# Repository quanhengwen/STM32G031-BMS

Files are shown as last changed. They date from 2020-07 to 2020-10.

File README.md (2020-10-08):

## STM32Gx31 BMS Board 
-----------------------------------------------------

### Problem
-------
A DIY Powerwall is the DIY construction of a pack of battery cells to create an energy store which can be used via inverters to power electrical items in the home. Generally cells are salvaged/second hand.

Lithium batteries need to be kept at the same voltage level across a parallel pack. This is done by balancing each cell in the pack to raise or lower its voltage to match the others.

Existing balancing solutions are available in the market place, but at a relatively high cost compared to the cost of the battery bank, so this project is to design a low-cost, simple featured BMS.

### Circuit explanation
------------------
Battery management system controlled by STM32G031K6 32bit microcontroller, the system has three separated units, power supply, analog digital conversion peripheral 
and communication unit. 

Power supply is connected directly to batteries meaning that we do not need additional external power source. Power supply main part is Texas Instruments integrated 
circuit TPS6107x which stands as a buck/boost converter generating stable 600 mA and 3.3 V at the output. All 4.7 uF capacitors connceted to TPS6107x chip are used to give the 
maximum power at the output. Two 4.7 uF X7R capacitors instead of one 10uF capacitor are better solution due to less value noise generation. 

The output voltage of the TPS6107x dc/dc converter can be adjusted with an external resistor divider. The typical value of the voltage at the FB pin is 500 mV. The maximum 
recommended value for the output voltage is 5.5 V. The current through the resistive divider should be about 100 times greater than the current into the FB pin. 

The typical current into the FB pin is 0.01 µA, and the voltage across R2 is typically 500 mV. Based on those two values, the recommended value for R2 should be lower than 500 kΩ, in
order to set the divider current at 1 µA or higher. Because of internal compensation circuitry, the value for this resistor should be in the range of 200 kΩ. The second parameter for
choosing the inductor is the desired current ripple in the inductor. Normally, it is advisable to work with a ripple of less than 20% of the average inductor current. A smaller
ripple reduces the magnetic hysteresis losses in the inductor, as well as  output voltage ripple and EMI. 

But in the same way, regulation time rises at load changes. Parameter f is the switching frequency and ΔIL is the ripple current in the inductor, i.e.,
40% ΔIL. In this example,the desired inductor has the value of 4 µH. With this calculated value and the calculated currents, it is possible to choose a suitable inductor. In typical 
applications, a 4.7-µH inductance is recommended. The device has been optimized to operate with inductance values between 2.2 µH and 10 µH.

Analog to digital conversion peripheral is used to take analog values from various sources, like NTC thermistors and batteries. These sources give us battery voltage and
battery temperature directly from battery connector and from the battery side. These two temperature points are added to calculate the temperature change between battery
connector and battery body. ADC peripheral has an ability to generate 12 bit and 16 bit battery voltage value due to operational amplifier circuit that generates triangle shape
signal making it better for microcontroller to take measurements with 4 extra bits. LMV321 is used as a main operational amplifier.

Devices are communicating in series, sharing measured values between each other. Main CPU is collecting voltage and temperature values from every unit and posting it to 
the PLC. System testing unit is using both half duplex and full duplex communication method. Half duplex method allows the system to communicate with another one but not 
in the same time whereas full duplex is making that possible. 

Half and full duplex communication main elements are Texas Instruments SN65HVD10 and SN65HVD73 transreceivers 
circuits. ICs datasheets recommend 10 kOhms pull up resistors for receiver input line and 10 kOhms pull down resistor for transmitter line. All outputs must be protected 
from electrostatic discharge. ESD protection is made using 10 Ohms resistors and zener diodes with Vz = 5 V disallowing signals to have values greater than 5 V.

### Project Documents 

[STM32G0 NUCLEO User Manual 1](https://www.st.com/resource/en/user_manual/dm00622380-stm32g0-nucleo-32-board-mb1455-stmicroelectronics.pdf)

[STM32G0 NUCLEO User Manual 2](https://www.st.com/resource/en/user_manual/dm00231744-stm32-nucleo32-boards-mb1180-stmicroelectronics.pdf)

[STM32G0 NUCLEO Reference Manual](https://www.st.com/resource/en/reference_manual/dm00371828-stm32g0x1-advanced-armbased-32bit-mcus-stmicroelectronics.pdf)

### KiCad Design 

_BMSv2.0 PCB Layout Design_

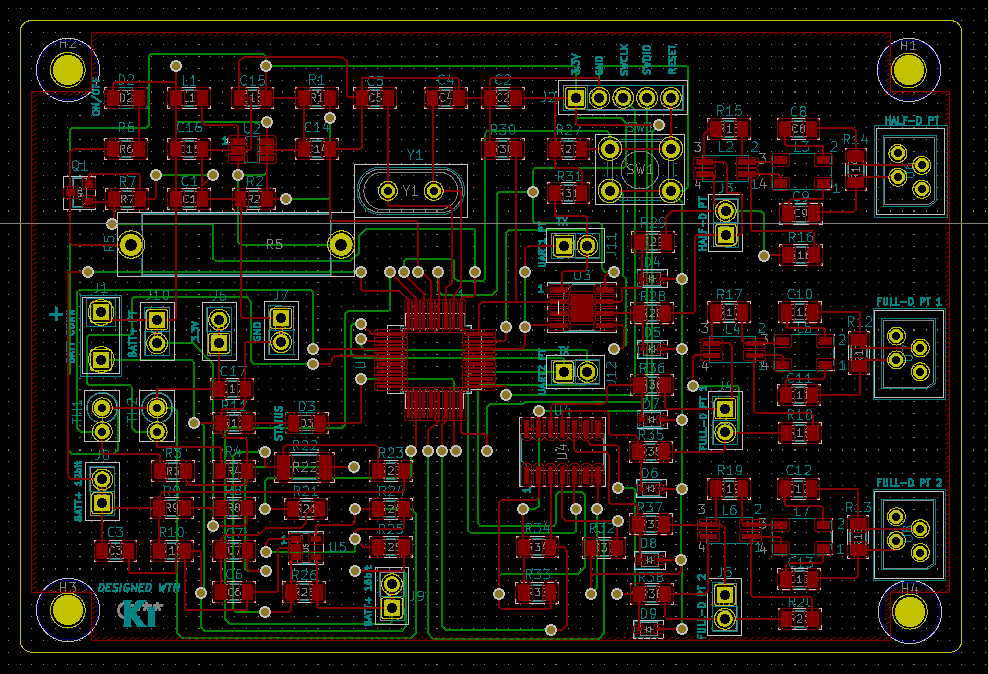
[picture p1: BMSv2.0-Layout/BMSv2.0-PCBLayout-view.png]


_BMSv2.0 PCB 3D View_

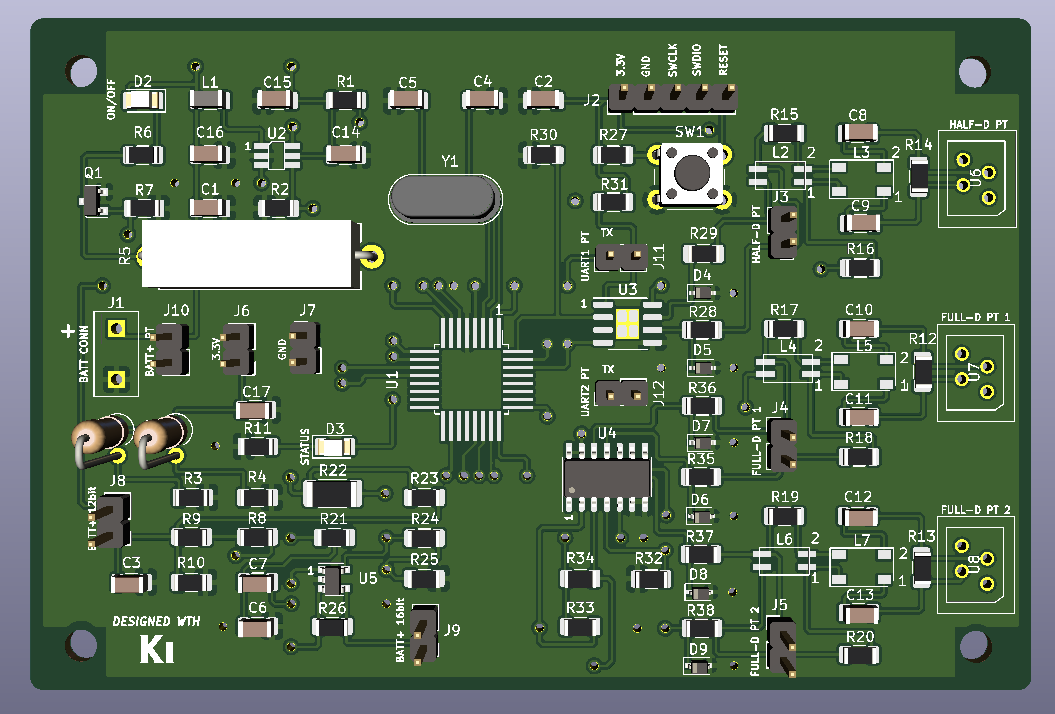
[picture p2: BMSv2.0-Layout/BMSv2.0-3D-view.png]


### Shortcomings and footnotes

1. Replace the boost converter with the buck/boost converter
2. Make the hole in the footprint for communication connector header
3. Replace 200k resistor with 180k resistor in the power supply block to generate correct voltage reference
4. Move the cooper pour layer from the output connectors
5. Put the interface to connect the board with PC
6. Change PWM output pin to TIM2_CH1
7. Move ADC pin from ADC1_IN1 pin (PA1) to clear the conflict with UART2 configuration
8. Using FreeRTOS, one task will take analog voltage and temperature values every milisecond, another task will send the data after it gets the request

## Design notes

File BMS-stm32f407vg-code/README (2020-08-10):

/--------------------------ADC peripheral explanation--------------------------------------
//PA0 and PA1 are analog input pins connected to measure battery voltage
//We assume that at PA0 pin (ADC_VOLT point) will be 16 bit battery voltage value
//at PA1 (ADC_VOLT_IN) will be 12 bit battery voltage value
//PA4 pin (ADC_TEMP1 point) is connected to voltage divider made by 10k resistor and thermistor in series
//PA5 pin (ADC_TEMP2 point) is connected aslo to simmilar voltage divider
//F_CPU is 16 MHz and we need to divide that value to cca 125 kHz to form ADCCLK
//for this purpose, we will use ADCx_SMPRx register (SMPx [2:0]) that holds the value how many cycles will th system sample
//any value and ADCx_CCR register (ADCPRE[17:16]) SMPx = 001 (15 cycles), ADCPRE = 11 ( PCK2 / 8) 
//ADCCLK -> 16 MHz / (15*8) = 133.3 kHz 
//We will allign data to the right so ALIGH bit in ADCx_CR2 will be cleared to 0, VREF is 2.56 V internally

//--------------------------System Nofitications----------------------------------------------
//type 0 for false ondition and 1 for true condition

//--------------------------TIM1 peripheral explanation---------------------------------------
//TIM1 is used to generate clock signal with frquency about 8 Hz, timer mode will be clear at compare match

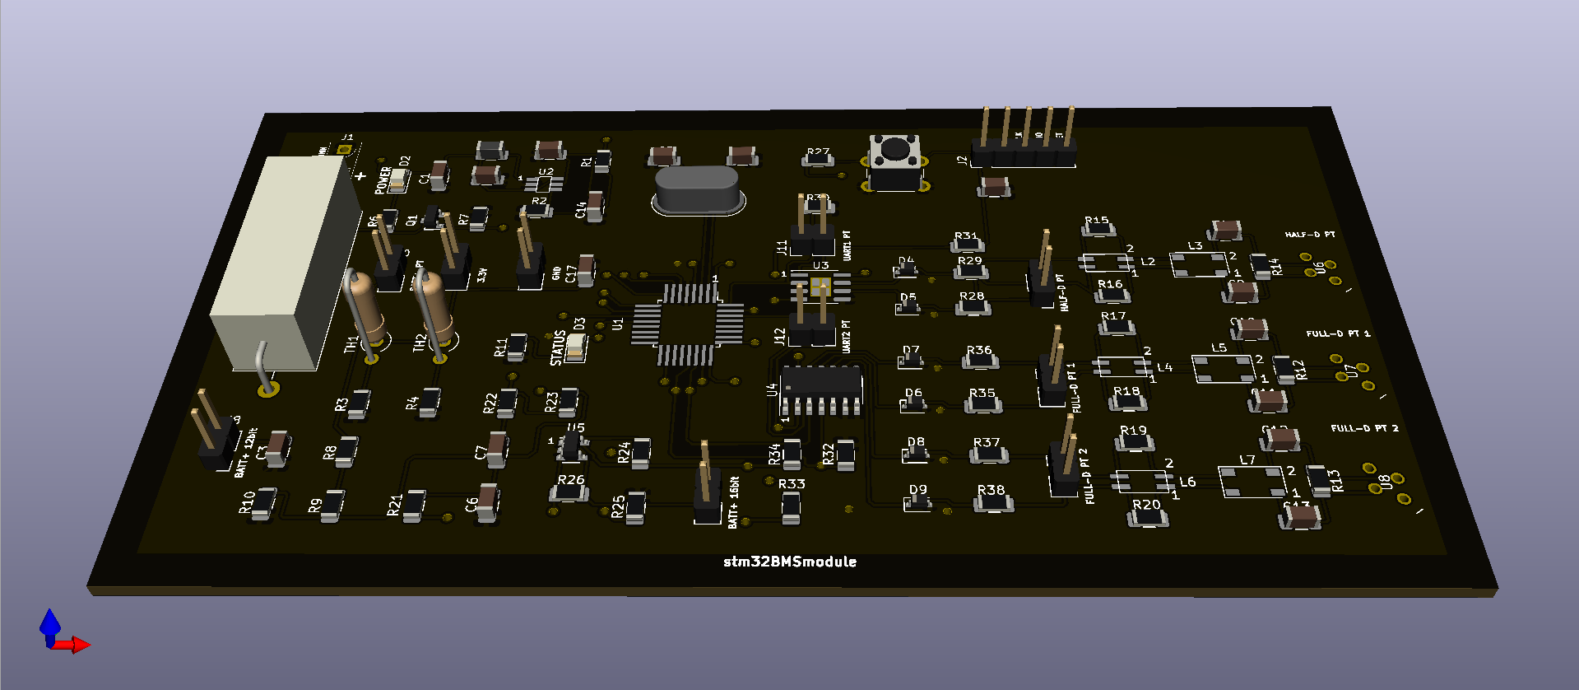
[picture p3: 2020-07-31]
BMS-layer-design-3Dview/STM32_BMS.png

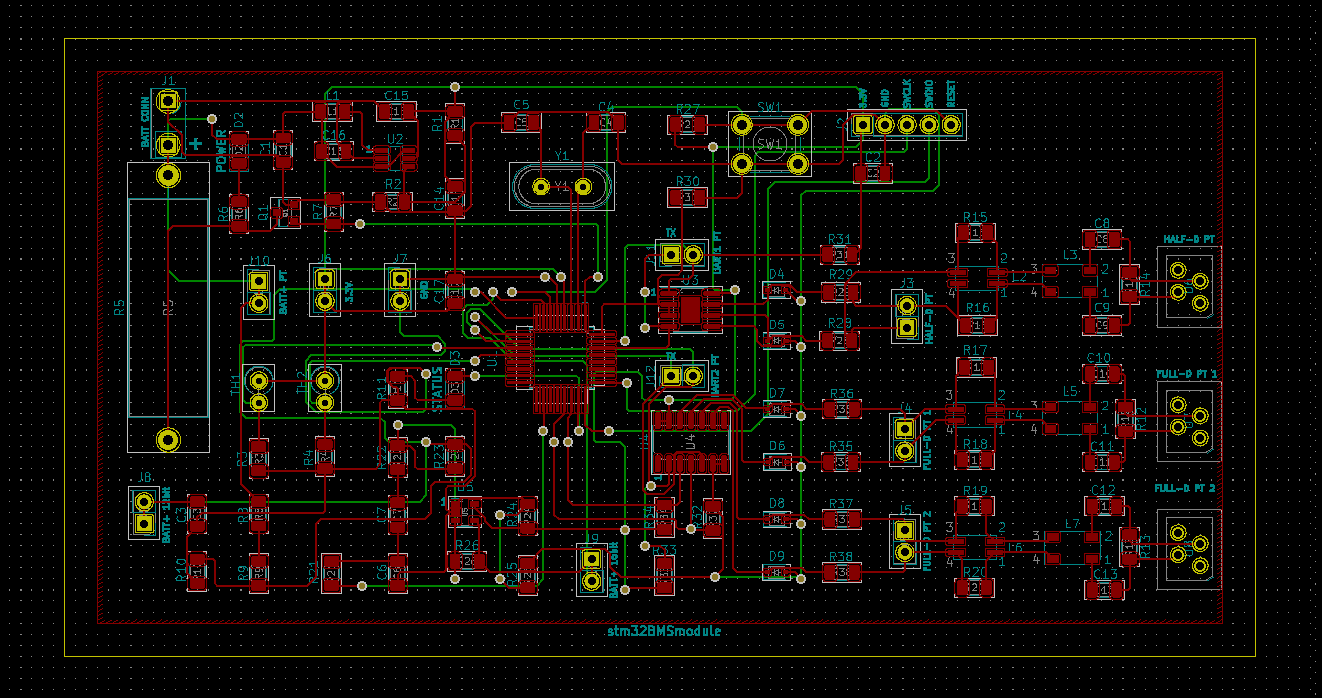
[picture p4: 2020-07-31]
BMS-layer-design-3Dview/BMS-layerView2.png

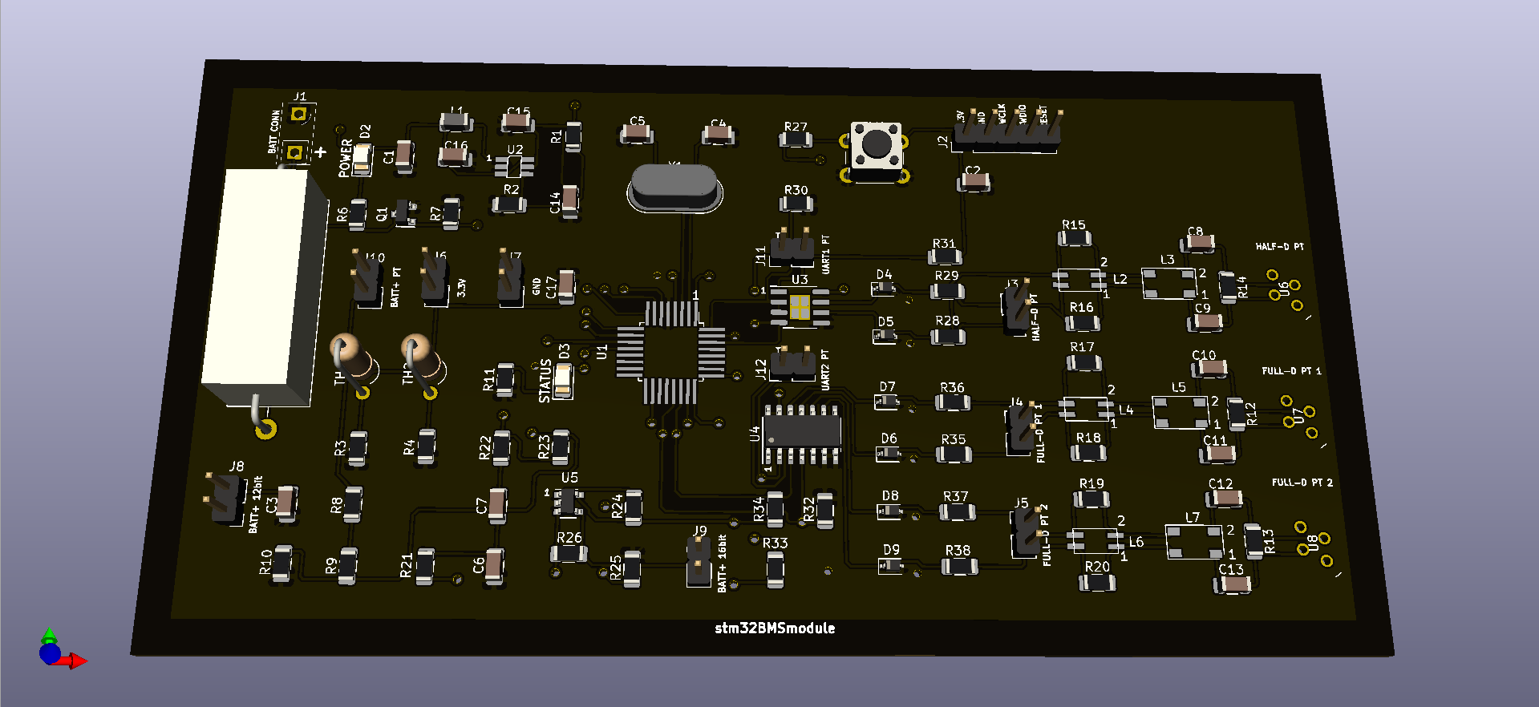
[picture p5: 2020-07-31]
BMS-layer-design-3Dview/STM32_BMS(2).png

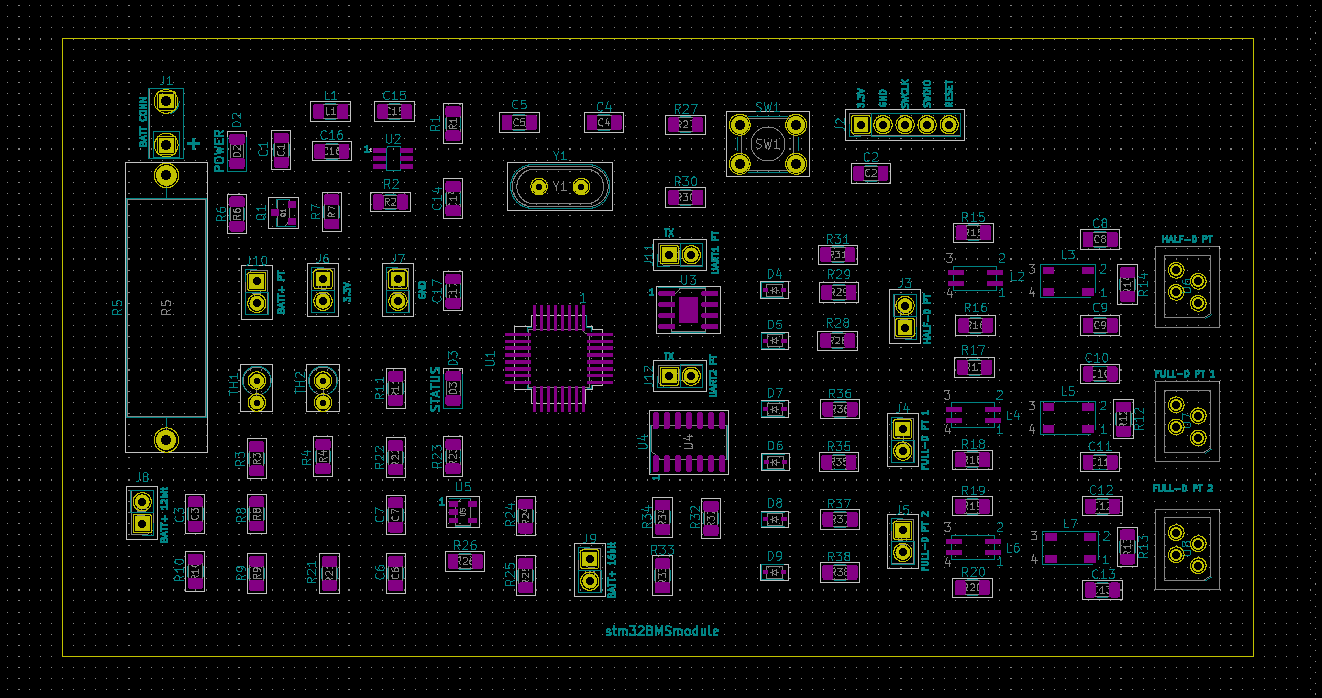
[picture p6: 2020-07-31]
BMS-layer-design-3Dview/BMS-layerView3.png

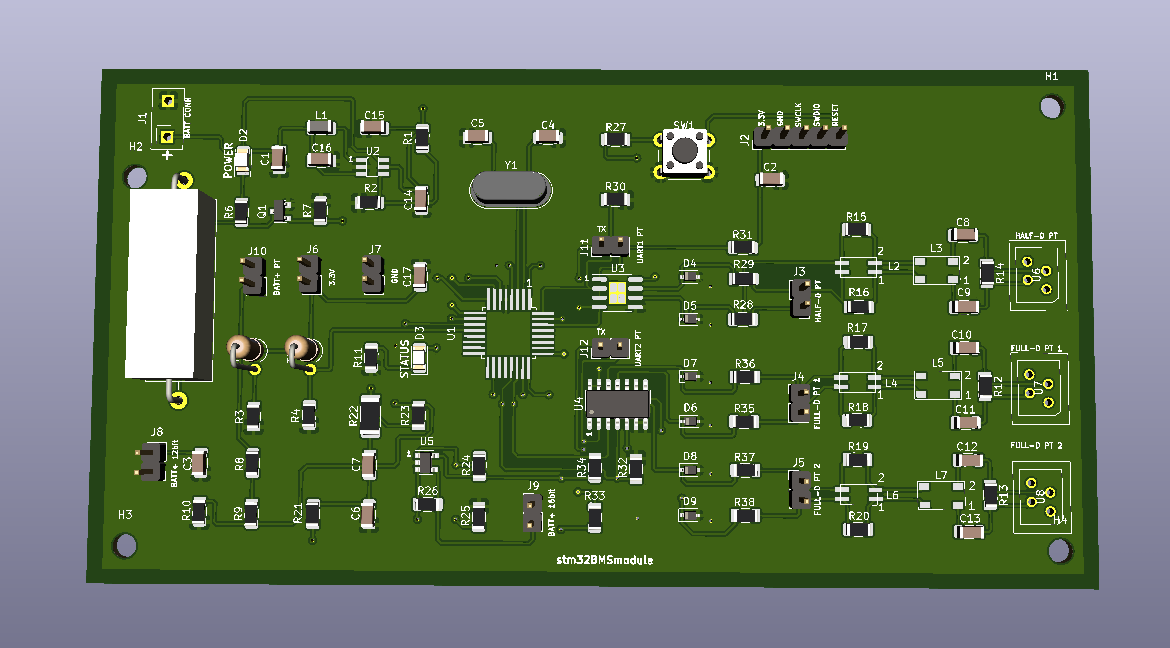
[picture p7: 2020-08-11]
BMS-layer-design-3Dview/BMS-3d view smaller.png

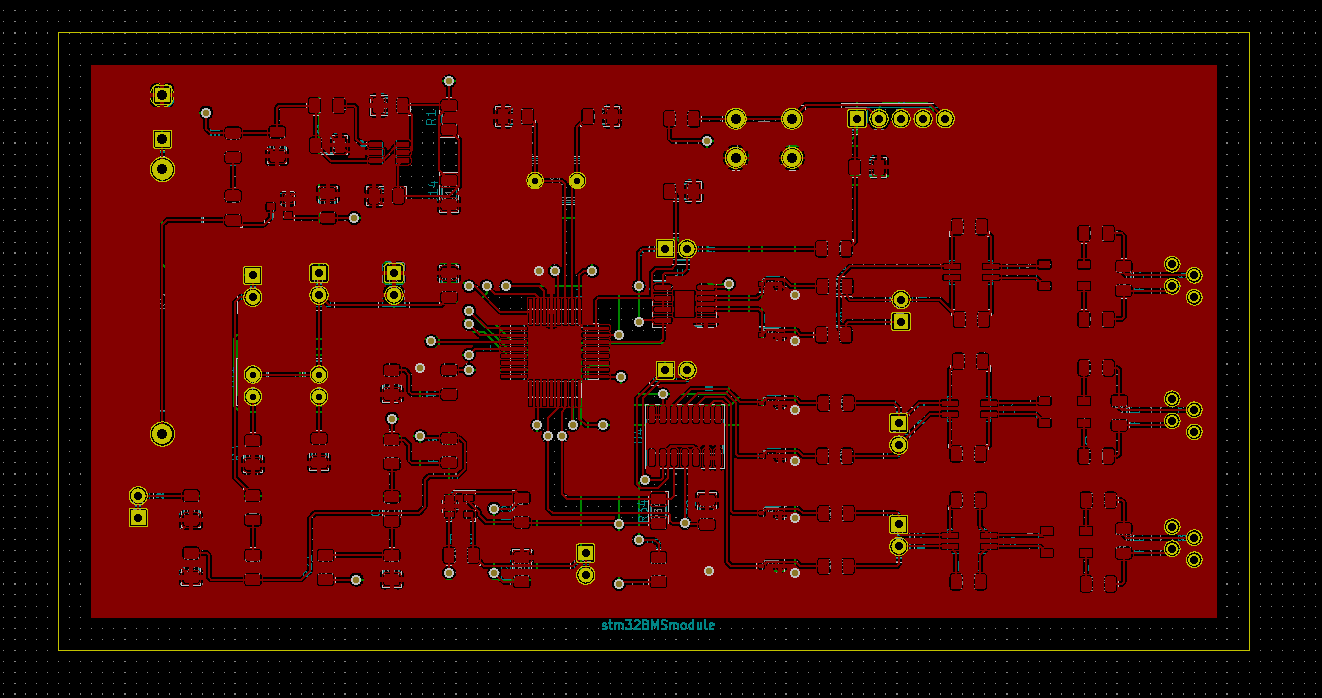
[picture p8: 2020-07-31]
BMS-layer-design-3Dview/BMS-layerView1.png

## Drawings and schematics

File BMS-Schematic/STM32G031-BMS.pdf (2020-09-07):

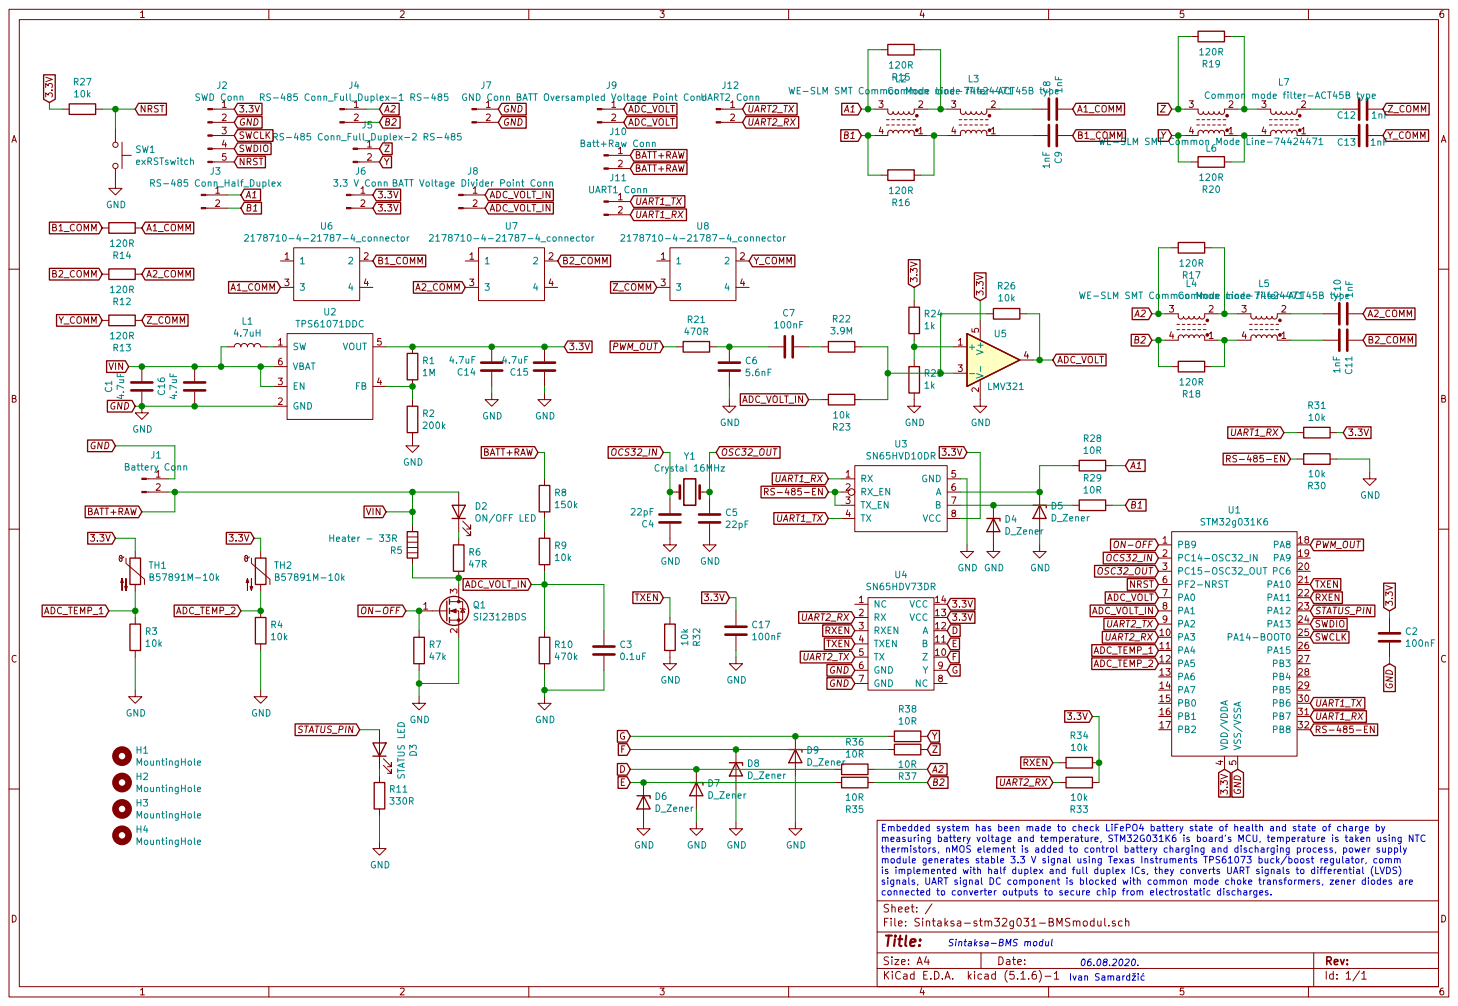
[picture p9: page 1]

J9 BATT Oversampled Voltage Point Conn D2ON/OFF LED

L7 Common mode filter-ACT45B type

L2 WE-SLM SMT Common Mode Line-74424471

L6 WE-SLM SMT Common Mode Line-74424471

L4 WE-SLM SMT Common Mode Line-74424471

Ivan Samardi Embedded system has been made to check LiFePO4 battery state of health and state of charge by
measuring battery voltage and temperature, STM32G031K6 is board's MCU, temperature is taken using NTC
thermistors, nMOS element is added to control battery charging and discharging process, power supply
module generates stable 3.3 V signal using Texas Instruments TPS61073 buck/boost regulator, comm
is implemented with half duplex and full duplex ICs, they converts UART signals to differential (LVDS)
signals, UART signal DC component is blocked with common mode choke transformers, zener diodes are
connected to converter outputs to secure chip from electrostatic discharges. 06.08.2020. Sintaksa-BMS modul
File: Sintaksa-stm32g031-BMSmodul.sch Sheet: /
Id: 1/1 Title:

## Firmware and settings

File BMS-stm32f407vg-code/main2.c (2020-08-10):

//--------------------------ADC peripheral explanation--------------------------------------
//PA0 and PA1 are analog input pins connected to measure battery voltage
//We assume that at PA0 pin (ADC_VOLT point) will be 16 bit battery voltage value
//at PA1 (ADC_VOLT_IN) will be 12 bit battery voltage value
//PA4 pin (ADC_TEMP1 point) is connected to voltage divider made by 10k resistor and thermistor in series
//PA5 pin (ADC_TEMP2 point) is connected aslo to simmilar voltage divider
//F_CPU is 16 MHz and we need to divide that value to cca 125 kHz to form ADCCLK
//for this purpose, we will use ADCx_SMPRx register (SMPx [2:0]) that holds the value how many cycles will th system sample
//any value and ADCx_CCR register (ADCPRE[17:16]) SMPx = 001 (15 cycles), ADCPRE = 11 ( PCK2 / 8) 
//ADCCLK -> 16 MHz / (15*8) = 133.3 kHz 
//We will allign data to the right so ALIGH bit in ADCx_CR2 will be cleared to 0, VREF is 2.56 V internally

//--------------------------System Nofitications----------------------------------------------
//type 0 for false ondition and 1 for true condition

//--------------------------TIM1 peripheral explanation---------------------------------------
//TIM1 is used to generate clock signal with frquency about 8 Hz, timer mode will be clear at compare match 

#include "stm32f4xx.h"                  // Device header
#include "RTE_Components.h"             // Component selection

//system predirectives
//Number of voltage readings to take before we take a temperature reading
#define TEMP_READING_LOOP_FREQ 16
#define OVERSAMPLE_LOOP 32
#define PIN0 0x1
#define PIN1 0x2
#define PIN4 0x4
#define PIN5 0x5
//Number of TIMER1 cycles between voltage reading checks (240 = approx 30 seconds)
#define BYPASS_COUNTER_MAX 240
uint8_t PINS [4] = {PIN0, PIN1, PIN4, PIN5};

//LED light patterns
#define GREEN_LED_PATTERN_STANDARD 0b00000000
#define GREEN_LED_PATTERN_BYPASS 0b01101100
#define GREEN_LED_PANIC 0b01010101
#define GREEN_LED_PATTERN_UNCONFIGURED 0b11101111

//forward method declarations
void initADC(void);
void ADC1_IRQHandler(void);
void initTimer1(void);
void TIM1_IRQHanlder(void);
inline void ledGreen(void);
inline void ledOff(void);
void bypass_off(void);
uint16_t Update_VCCMillivolts(void);

//system global variable definitions
volatile uint32_t analogVal[OVERSAMPLE_LOOP];
volatile uint8_t analogValIndex;
volatile uint8_t buffer_ready = 0;
volatile int skipNextADC = 0;
volatile uint8_t reading_count = 0;
volatile uint32_t temperature_probe = 0;
volatile uint32_t last_raw_adc = 0;
volatile uint8_t green_pattern = GREEN_LED_PATTERN_STANDARD;
volatile int flash_green = 0;
volatile int ByPassEnabled = 0;
volatile uint16_t ByPassVCCMillivolts = 0;
volatile uint8_t ByPassCounter = 0;
volatile uint16_t targetByPassVoltage = 0;

void initADC(void){
	//Enable clock acces to GPIOA module
	RCC->AHB1ENR |= 0x1;
	//Declare PA0, PA1, PA4 and PA5 as analog input mode pins
	GPIOA->MODER |= 0xF0F;
	//Enable clock access to ADC1 module (represented by 8th bit in APB2ENR reg)
	RCC->APB2ENR |= 0x100;
	//Disable the ADC module
	ADC1->CR2 = 0;
 //Set the ADCCLK value, 133.3 kHz
	ADC1->SMPR1 |= 0x1;
	ADC->CCR |= 0x30000;
	//Channel number CH1 assigned as the 1st in the sequence to be converted
	//PA0 is connected to ADC1 input module
	ADC1->SQR3 = PINS[0];
	//Interrupt enable for ADC1 end of conversion
	ADC1->CR1 |= 0x10;
	//Enable ADC1 module and set continouns sequence mode
	ADC1->CR2 |= 0x3;
}

void ADC1_IRQHandler(void){
	//Interrupt servie routine for ADC completion
	uint32_t value = 0;
	//If we skip this ADC reading, quit ISR here
  if (skipNextADC) {
    skipNextADC = 0;
    return;
  }
		if (reading_count == TEMP_READING_LOOP_FREQ ) {
    reading_count = 0;

    //We reduce the value by 512 as we have a DC offset we need to remove
    temperature_probe = value;

    //Connect the next pin to take the value
    //ADMUX = B10010011
			//Connect GPIOA PIN 0 to th ADC1 module input
				ADC1->SQR3 = PINS[0];
			
				/*if(ADC1->SQR3 == PINS[0]){
					ADC1->SQR3 = PINS[1];
				}
				else if(ADC1->SQR3 == PINS[1]){
					ADC1->SQR3 = PINS[2];
				}
				else if(ADC1->SQR3 == PINS[2]){
					ADC1->SQR3 = PINS[3];
				}
				else if(ADC1->SQR3 == PINS[3]){
					ADC1->SQR3 = PINS[0];
				}
				*/
			
    //Set skipNextADC to delay the next TIMER2 call to ADC reading to allow the ADC to settle after changing MUX
    skipNextADC = 1;

  }
		 else {

    //Populate the rolling buffer with values from the ADC
    last_raw_adc = value;
    analogVal[analogValIndex] = value;

    analogValIndex++;

    if (analogValIndex == OVERSAMPLE_LOOP) {
      analogValIndex = 0;
      buffer_ready = 1;
    }

    reading_count++;

    if (reading_count == TEMP_READING_LOOP_FREQ) {
      //use ADC0 for temp probe input on next ADC loop
						
					
      //ADMUX = B10010000;
							//Assuming PA0 is connected to ADC1 module input and we need to connect PA1 to the input and so on
					ADC1->SQR3 = PINS[2];
					
					/*
							if(ADC1->SQR3 == PINS[0]){
								ADC1->SQR3 = PINS[1];
							}
							else if(ADC1->SQR3 == PINS[1]){
								ADC1->SQR3 = PINS[2];
							}
							else if(ADC1->SQR3 == PINS[2]){
								ADC1->SQR3 = PINS[3];
							}
							else if(ADC1->SQR3 == PINS[3]){
								ADC1->SQR3 = PINS[0];
							}
					*/
					
      //Set skipNextADC to delay the next TIMER1 call to ADC reading to allow the ADC to settle after changing MUX
      skipNextADC = 1;
    }
  }
}

void initTimer1(void){
	//Enable clock access to TIM1
	RCC->APB2ENR |= 0x1;
	//Define clock signal prescaler, generate 8 Hz signal 
	//F_OSC = 16 MHz, prescaler = 16000 * 125 = 2 MHz equals 8 ticks per second
	TIM1->PSC = 16000 - 1;
	TIM1->ARR = 125 - 1;
	//Set the value to be compared with counter register
	TIM1->CCR1 = 64;
	//Interrupt request is to be generated
	TIM1->DIER |= 0x1;
	//Toggle OCx pin when CNT reg reaches CCR reg
	TIM1->CCMR1 |= 0x30;
	//Select active high polarity and enable the output
	TIM1->CCER |= 0x1;
	//Enable the timer
	TIM1->CR1 |= 0x1;
}

void TIM1_IRQHanlder(void){
	 if (green_pattern == 0) {
    if (flash_green)  {
      ledGreen();
    }
    flash_green = 0;
  } else {
    ///Rotate pattern
    green_pattern = (uint8_t)(green_pattern << 1) | (green_pattern >> 7);
				}
		if (green_pattern & 0x01) {
      ledGreen();
    } else {
      ledOff();
    }  
				 if (ByPassEnabled) {

    //TODO: We need to add in code here to check we don't overheat

    //This must go above the following "if (ByPassCounter > 0)" statement...
    if (ByPassCounter == 0 && analogValIndex == 0) {
      //We are in bypass and just finished an in-cycle voltage measurement
      ByPassVCCMillivolts = Update_VCCMillivolts();

      if (targetByPassVoltage >= ByPassVCCMillivolts) {
        //We reached the goal
        bypass_off();
      } else {
        //Try again
        ByPassCounter = BYPASS_COUNTER_MAX;
      }
    }

    if (ByPassCounter > 0)
    {
      //We are in ACTIVE BYPASS mode - the RESISTOR will be ACTIVE + BURNING ENERGY
      ByPassCounter--;
      //digitalWrite(PB4, HIGH);
						//ON-OFF pin at PB9 pin
					//Enable clock access to GPIOB
						RCC->AHB1ENR |= 0x2;
					//Declare PB9 as output mode pin
					GPIOB->MODER |= 0x40000;
					//Set PB9 at HIGH state
					GPIOB->BSRR |= 0x200;
      if (ByPassCounter == 0)
      {
        //We have just finished this timed ACTIVE BYPASS mode, disable resistor
        //and measure resting voltage now before possible re-enable.
        //digitalWrite(PB4, LOW);
								//Enable clock access to GPIOB
								RCC->AHB1ENR |= 0x2;
								//Declare PB9 as output mode pin
								GPIOB->MODER |= 0x40000;
								//Set PB9 at LOW state
								GPIOB->BSRR |= 0x2000000;
        //Reset voltage ADC buffer
        analogValIndex = 0;
      }
    }

  } else {
    //Safety check we ensure bypass is always off if not enabled
    //digitalWrite(PB4, LOW);
				//Enable clock access to GPIOB
				RCC->AHB1ENR |= 0x2;
				//Declare PB9 as output mode pin
				GPIOB->MODER |= 0x40000;
				//Set PB9 at LOW state
				GPIOB->BSRR |= 0x2000000;
  }

  if (green_pattern == 0) {
    ledOff();
  }


  //trigger ADC reading
  //ADCSRA |= (1 << ADSC);
		//Enable clock access to GPIOA module
		RCC->AHB1ENR |= 0x1;
		//Enable clock access to ADC1 module (represented by 8th bit in APB2ENR reg)
		RCC->APB2ENR |= 0x100;
		//Trigger ADC1 module
		ADC1->CR2 |= 0x40000000;
}
inline void ledGreen() {
  //DDRB |= (1 << DDB1);
  //PORTB |=  (1 << PB1);
		//Enable clock access to GPIOA
		RCC->AHB1ENR |= 0x1;
		//Define PA12 as output mode pin
		GPIOA->MODER |= 0x1000000;
		//Set PA12 at HIGH state
		GPIOA->BSRR |= 0x1000;
}

inline void ledOff() {
  //Low
  //DDRB |= (1 << DDB1);
  //PORTB &= ~(1 << PB1);
  //Enable clock access to GPIOA
		RCC->AHB1ENR |= 0x1;
		//Define PA12 as output mode pin
		GPIOA->MODER |= 0x1000000;
		//Set PA12 at LOW state
		GPIOA->BSRR |= 0x10000000;
}
void bypass_off(void){
  targetByPassVoltage = 0;
  ByPassCounter = 0;
  ByPassEnabled = 0;
  green_pattern = GREEN_LED_PATTERN_STANDARD;
}

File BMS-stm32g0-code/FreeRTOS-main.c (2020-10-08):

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
/* Includes ------------------------------------------------------------------*/
#include "main.h"
#include "cmsis_os.h"
#include "freertos.h"
#include "stdio.h"
#include "stdint.h"
ADC_HandleTypeDef hadc1;
UART_HandleTypeDef huart1;
UART_HandleTypeDef huart2;
osThreadId Task1Handle;
osThreadId Task2Handle;
osThreadId Task3Handle;
osSemaphoreId BinarySemHandle;
uint16_t voltageValue = 0;
uint16_t temperatureValue = 0;
uint8_t system_default_address = 0x20;
uint16_t voltage = 0;
uint16_t temperature = 0;
void SystemClock_Config(void);
static void MX_GPIO_Init(void);
static void MX_USART2_UART_Init(void);
static void MX_ADC1_Init(void);
static void MX_USART1_UART_Init(void);
void UART_Task(void const * argument);
void ADC_Volt_Task(void const * argument);
void ADC_Temp_Task(void const * argument);

/**
  * @brief  The application entry point.
  * @retval int
  */
int main(void)
{
  /* MCU Configuration--------------------------------------------------------*/

  /* Reset of all peripherals, Initializes the Flash interface and the Systick. */
  HAL_Init();

  /* Configure the system clock */
  SystemClock_Config();

  /* Initialize all configured peripherals */
  MX_GPIO_Init();
  MX_USART2_UART_Init();
  MX_ADC1_Init();
  MX_USART1_UART_Init();
  /* USER CODE BEGIN RTOS_MUTEX */
  /* add mutexes, ... */
  /* USER CODE END RTOS_MUTEX */

  /* Create the semaphores(s) */
  /* definition and creation of BinarySem */
  osSemaphoreDef(BinarySem);
  BinarySemHandle = osSemaphoreCreate(osSemaphore(BinarySem), 1);

  /* USER CODE BEGIN RTOS_SEMAPHORES */
  /* add semaphores, ... */
  /* USER CODE END RTOS_SEMAPHORES */

  /* USER CODE BEGIN RTOS_TIMERS */
  /* start timers, add new ones, ... */
  /* USER CODE END RTOS_TIMERS */

  /* USER CODE BEGIN RTOS_QUEUES */
  /* add queues, ... */
  /* USER CODE END RTOS_QUEUES */

  /* Create the thread(s) */
  /* definition and creation of Task1 */
  osThreadDef(Task1, UART_Task, osPriorityNormal, 0, 128);
  Task1Handle = osThreadCreate(osThread(Task1), NULL);

  /* definition and creation of Task2 */
  osThreadDef(Task2, ADC_Volt_Task, osPriorityNormal, 0, 128);
  Task2Handle = osThreadCreate(osThread(Task2), NULL);

  /* definition and creation of Task3 */
  osThreadDef(Task3, ADC_Temp_Task, osPriorityNormal, 0, 128);
  Task3Handle = osThreadCreate(osThread(Task3), NULL);

  /* USER CODE BEGIN RTOS_THREADS */
  /* add threads, ... */
  /* USER CODE END RTOS_THREADS */

  /* Start scheduler */
  osKernelStart();

  /* We should never get here as control is now taken by the scheduler */
  /* Infinite loop */
  /* USER CODE BEGIN WHILE */
  while (1)
  {
    /* USER CODE END WHILE */

    /* USER CODE BEGIN 3 */
  }
  /* USER CODE END 3 */
}

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
/* USER CODE BEGIN Header_UART_Task */
/**
  * @brief  Function implementing the Task1 thread.
  * @param  argument: Not used
  * @retval None
  */
/* USER CODE END Header_UART_Task */
void UART_Task(void const * argument)
{
  /* USER CODE BEGIN 5 */
  /* Infinite loop */
  while(1)
  {
	  //priting the entry string
	  printf("The system is sending the packets...\n");
	  //Enable transmission
	  HAL_GPIO_WritePin(GPIOA, GPIO_PIN_10, GPIO_PIN_SET);
	  //wait for 1ms
	  osDelay(1);
	  //Send the system address
	  HAL_UART_Transmit(&huart2, &system_default_address, sizeof(system_default_address), HAL_MAX_DELAY);
	  //wait for 1ms
	  //HAL_Delay(1);
	  //Send the system voltage value
	  HAL_UART_Transmit(&huart2, &voltage, sizeof(voltage), HAL_MAX_DELAY);
	  //wait for 1ms
	  //HAL_Delay(1);
	  //Send the system temperature value
	  HAL_UART_Transmit(&huart2, &temperature, sizeof(temperature), HAL_MAX_DELAY);
	  //Disable transmission
	  HAL_GPIO_WritePin(GPIOA, GPIO_PIN_10, GPIO_PIN_RESET);
	  //10000 ms delay
      	osDelay(10000);
  }
  /* USER CODE END 5 */
}

/* USER CODE BEGIN Header_ADC_Volt_Task */
/**
* @brief Function implementing the Task2 thread.
* @param argument: Not used
* @retval None
*/
/* USER CODE END Header_ADC_Volt_Task */
void ADC_Volt_Task(void const * argument)
{
  /* USER CODE BEGIN ADC_Volt_Task */
  /* Infinite loop */
  while(1)
  {
	  //priting the entry string
	  printf("The system is taking voltage value...\n");
	  //Define ADC parameters
	  hadc1.Instance = ADC1;
	  ADC_ChannelConfTypeDef sConfig = {0};
	  sConfig.Channel = ADC_CHANNEL_1;
	  //Start ADC
	  HAL_ADC_Start(&hadc1);
	  //Poll ADC
	  HAL_ADC_PollForConversion(&hadc1, 100);
	  //calculate analog and decimal values
	  voltage = (HAL_ADC_GetValue(&hadc1));
	  //5000 ms delay
	  osDelay(5000);
  }
  /* USER CODE END ADC_Volt_Task */
}

/* USER CODE BEGIN Header_ADC_Temp_Task */
/**
* @brief Function implementing the Task3 thread.
* @param argument: Not used
* @retval None
*/
/* USER CODE END Header_ADC_Temp_Task */
void ADC_Temp_Task(void const * argument)
{
  /* USER CODE BEGIN ADC_Temp_Task */
  /* Infinite loop */
  while(1)
  {
	  //priting the entry string
	  printf("The system is taking temperature value...\n");
	  //Define ADC parameters
	  hadc1.Instance = ADC1;
	  ADC_ChannelConfTypeDef sConfig = {0};
	  sConfig.Channel = ADC_CHANNEL_4;
	  //Start ADC
	  HAL_ADC_Start(&hadc1);
	  //Poll ADC
	  HAL_ADC_PollForConversion(&hadc1, 100);
	  //calculate analog and decimal values
	  temperature = (HAL_ADC_GetValue(&hadc1));
	  //5000 ms delay
	  osDelay(5000);
  }
  /* USER CODE END ADC_Temp_Task */
}

/**
  * @brief  Period elapsed callback in non blocking mode
  * @note   This function is called  when TIM1 interrupt took place, inside
  * HAL_TIM_IRQHandler(). It makes a direct call to HAL_IncTick() to increment
  * a global variable "uwTick" used as application time base.
  * @param  htim : TIM handle
  * @retval None
  */
void HAL_TIM_PeriodElapsedCallback(TIM_HandleTypeDef *htim)
{
  if (htim->Instance == TIM1) {
    HAL_IncTick();
  }
}

/**
  * @brief  This function is executed in case of error occurrence.
  * @retval None
  */
void Error_Handler(void)
{
  /* USER CODE BEGIN Error_Handler_Debug */
  /* User can add his own implementation to report the HAL error return state */

  /* USER CODE END Error_Handler_Debug */
}

#ifdef  USE_FULL_ASSERT
/**
  * @brief  Reports the name of the source file and the source line number
  *         where the assert_param error has occurred.
  * @param  file: pointer to the source file name
  * @param  line: assert_param error line source number
  * @retval None
  */
void assert_failed(uint8_t *file, uint32_t line)
{
  /* USER CODE BEGIN 6 */
  /* User can add his own implementation to report the file name and line number,
     tex: printf("Wrong parameters value: file %s on line %d\r\n", file, line) */
  /* USER CODE END 6 */
}
#endif /* USE_FULL_ASSERT */

/************************ (C) COPYRIGHT STMicroelectronics *****END OF FILE****/

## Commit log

2020-08-06 BMS module schematic
2020-08-06 Working Gerbers
    [Sintaksa-stm32g031-BMSmodul-B_Cu.gbr, Sintaksa-stm32g031-BMSmodul-B_Mask.gbr, Sintaksa-stm32g031-BMSmodul-B_SilkS.gbr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]
2020-08-07 stm32f4 discovery BMS code
2020-08-10 main BMS code
2020-08-11 BMS 3d view smaller size photo
2020-09-07 KiCad Layout design photos
2020-09-07 BMS schematic
2020-09-14 ADC_VOLT_IN pin testing
2020-09-14 ADC_TEMP1 pin test
2020-09-14 status LED test
2020-09-14 ON-OFF pin testing
2020-09-17 UART1 peripheral test
2020-10-08 UART sharing ADC temp and volt values using tasks

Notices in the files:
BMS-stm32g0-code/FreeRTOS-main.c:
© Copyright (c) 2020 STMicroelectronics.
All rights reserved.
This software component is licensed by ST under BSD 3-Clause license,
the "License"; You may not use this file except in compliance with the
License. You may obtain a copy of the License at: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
